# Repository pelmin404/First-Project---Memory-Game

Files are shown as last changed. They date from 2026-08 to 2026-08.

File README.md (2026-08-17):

# First-Project_Memory-Game

A small circuit board Simon type game based on Arduino's ATmega328P

This game is made to improve short term memory under load and just to spend time when bored.

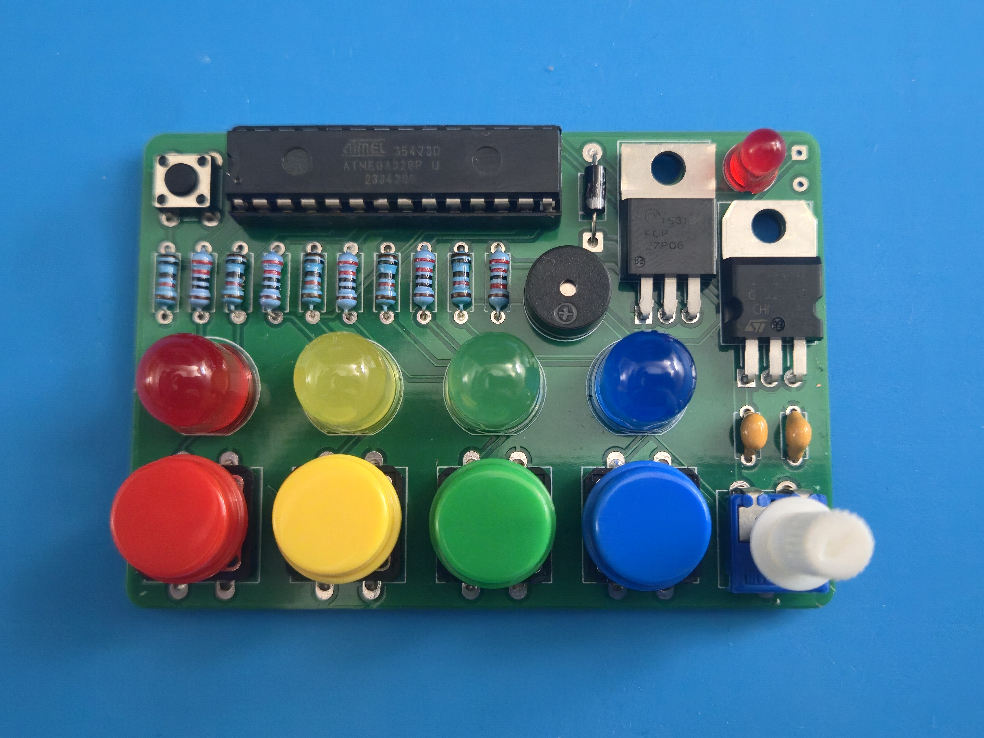
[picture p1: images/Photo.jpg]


# 🛠️ Technical Details
### The MCU is programmed with an internal 8 MHz clock

It works on the same MCU found in Arduino UNO R3 and a few others. It can be powered by a DC power source ranging from 7 to 35 volts, the files provided use a 9V input as an example. In the final iteration I added a power indicator with a MOSFET and an LED which is brighter the higher the input voltage with 9 volts being barely visible in order to indicate when the battery is almost at 7 volts, which may cause MCU instability. In order for the indicator system to work properly the combined voltage drop of the indicator LED and the following diode D6 should be as close as possible to the drop of the L7805CV or about 2 volts. The sound control potentiometer can be either logarithmic or regular, depending on preference. The small button on the top left corner of the board is used to reset the MCU and therefore the game if you encounter an electrical issue causing MCU instability or just really don't want to lose. The circular solder pad for the power source is ground (-).

## ⚠️ Please note that some mechanical switches may produce a noisy signal that forces the MCU to think you pressed the button multiple times

# 📼 Video examples

[Win example](https://github.com/pelmin404/First-Project_Memory-Game/blob/main/Videos/Win%20example.mp4)

[Loss example](https://github.com/pelmin404/First-Project_Memory-Game/blob/main/Videos/Loss%20example.mp4)

[Power indicator](https://github.com/pelmin404/First-Project_Memory-Game/blob/main/Videos/Power%20indicator.mp4)

# ⚙️ Part List

- [ATMEGA328P-PU](https://www.digikey.com/en/products/detail/microchip-technology/ATMEGA328P-PU/1914589)
- [MCU socket](https://www.digikey.com/en/products/detail/3m/4828-3004-CP/1133633?s=N4IgTCBcDaIMwFkCsAWAHABgLQDkAiIAugL5A)
- [Leo Sales Ltd. 10mm 2x6 Colors LED](https://www.microcenter.com/product/511285/leo-sales-ltd-10mm-2x6-colors-led)
- [Tactile Button Assortment](https://www.microcenter.com/product/427684/tactile-button-assortment)
- [L7805CV]()
- [5V 1.5A Linear Voltage Regulator - 7805 TO-220](https://www.adafruit.com/product/2164)
- 5 10 kΩ resistors
- 4 220 Ω resistors
- 1 22 kΩ resistor
- 1 0.33 μF capacitor
- 1 0.1 μF capacitor
- [Leo Sales Ltd. PCB Mounted Piezo Buzzer - 9x5.5mm (10 Pack)](https://www.microcenter.com/product/677928/leo-sales-ltd-pcb-mounted-piezo-buzzer-9x55mm-(10-pack))
- A 10 kΩ potentiometer, I used an ACP CA9-V10 footprint
- A 6 mm THT momentary push button
- Any 5 mm LED and a diode that fits the footprint, that have a total voltage drop of 2 V

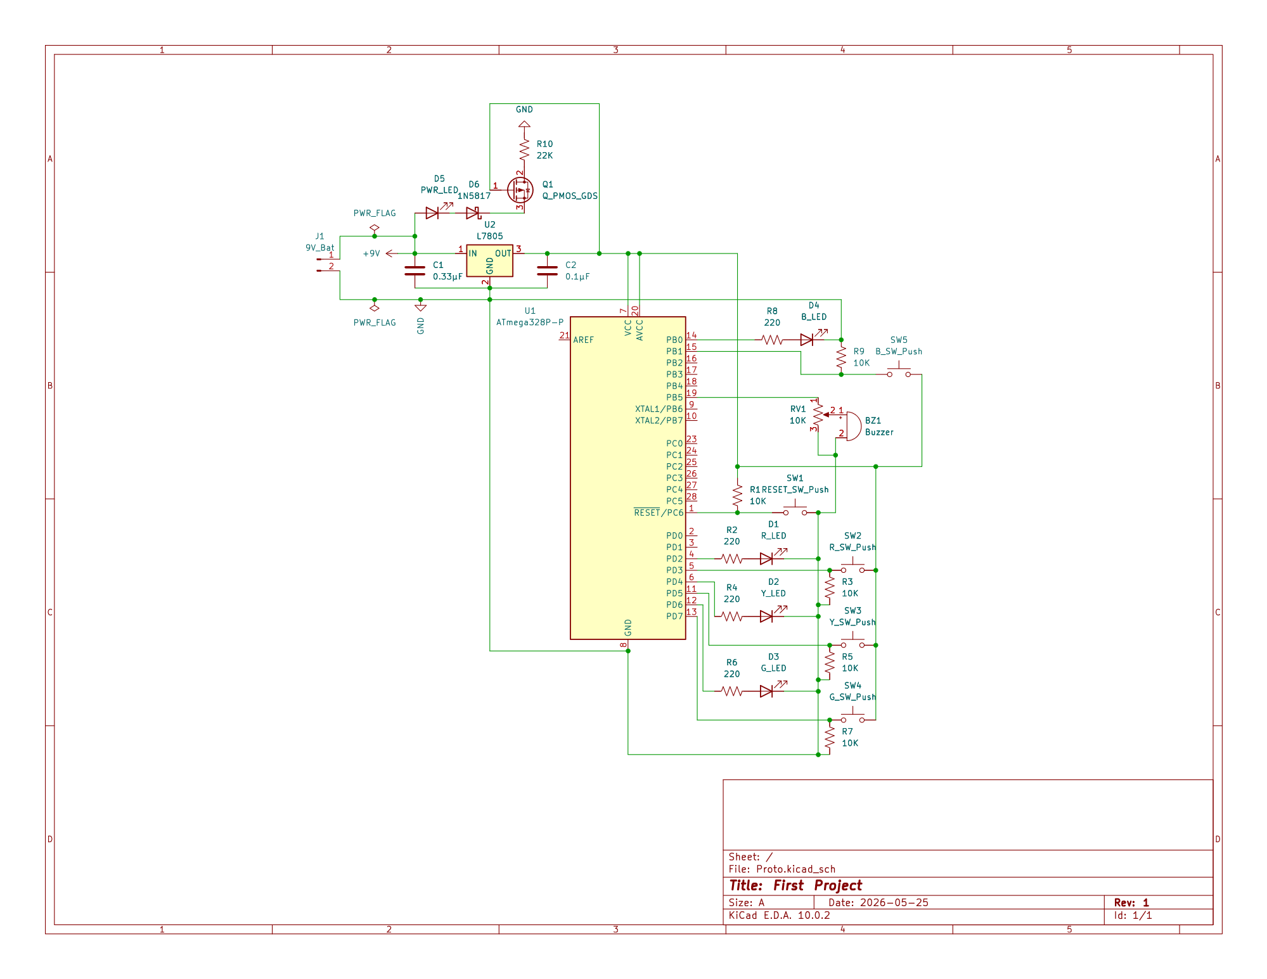
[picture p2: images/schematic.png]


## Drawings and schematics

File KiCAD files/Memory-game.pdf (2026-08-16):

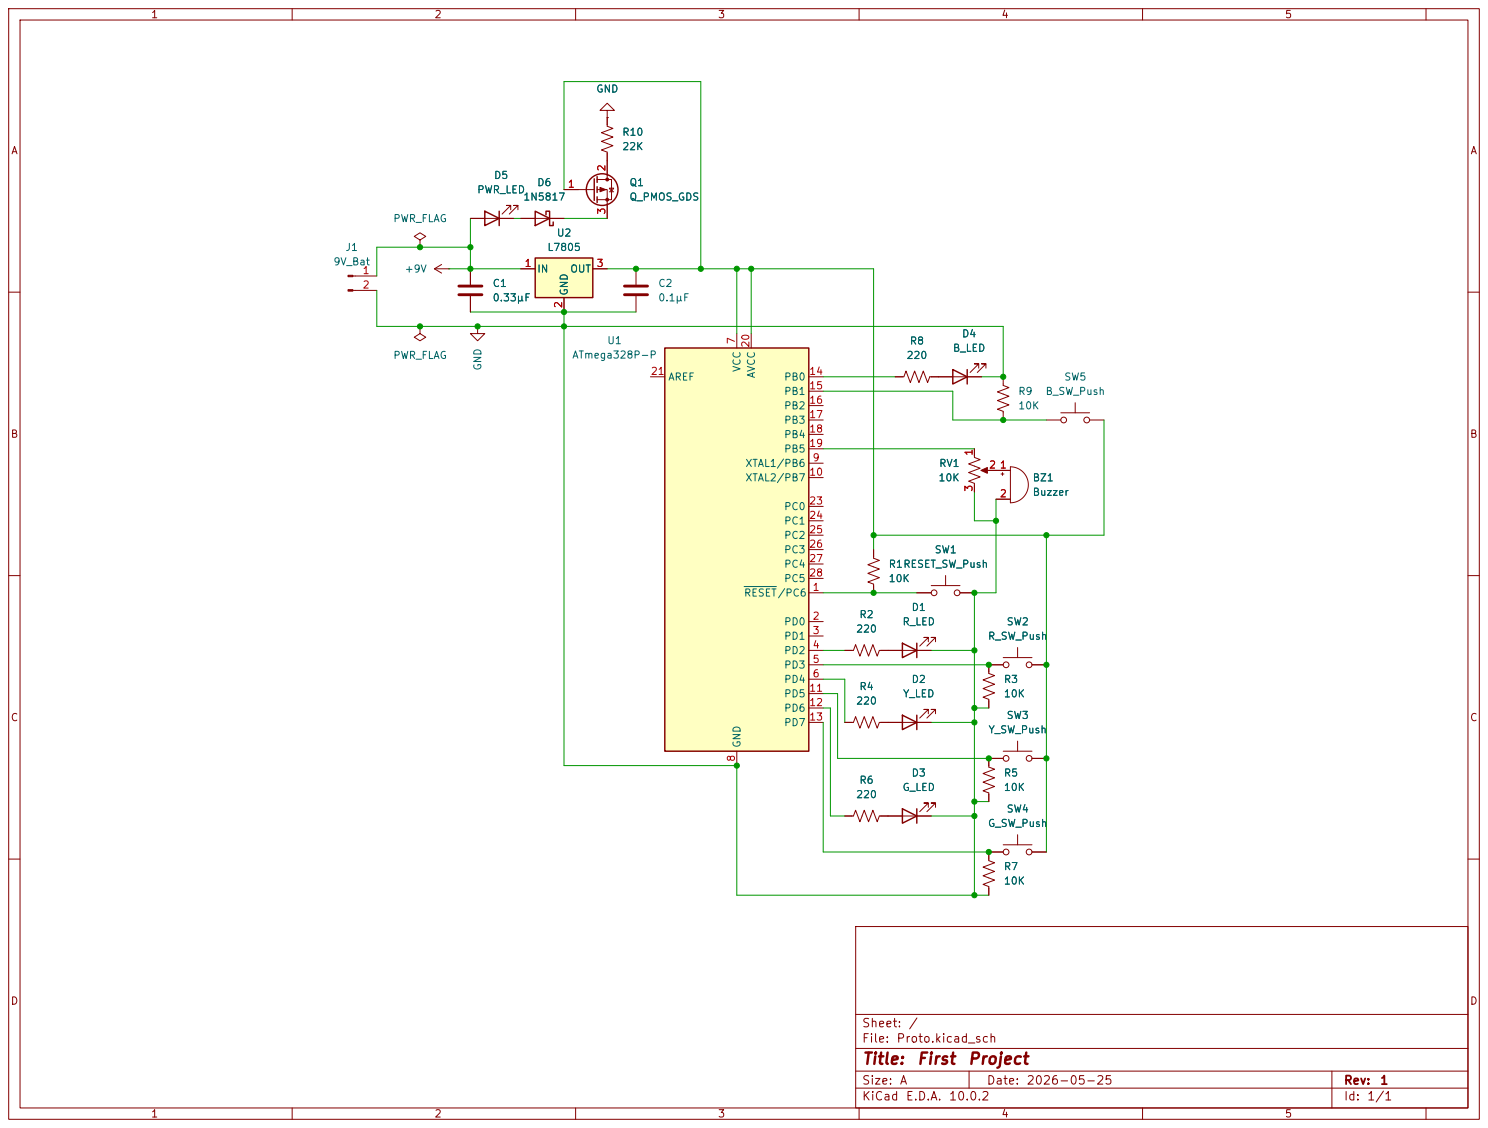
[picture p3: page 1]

Size: A | Rev: 1
KiCad E.D.A. 10.0.2 | Id: 1/1

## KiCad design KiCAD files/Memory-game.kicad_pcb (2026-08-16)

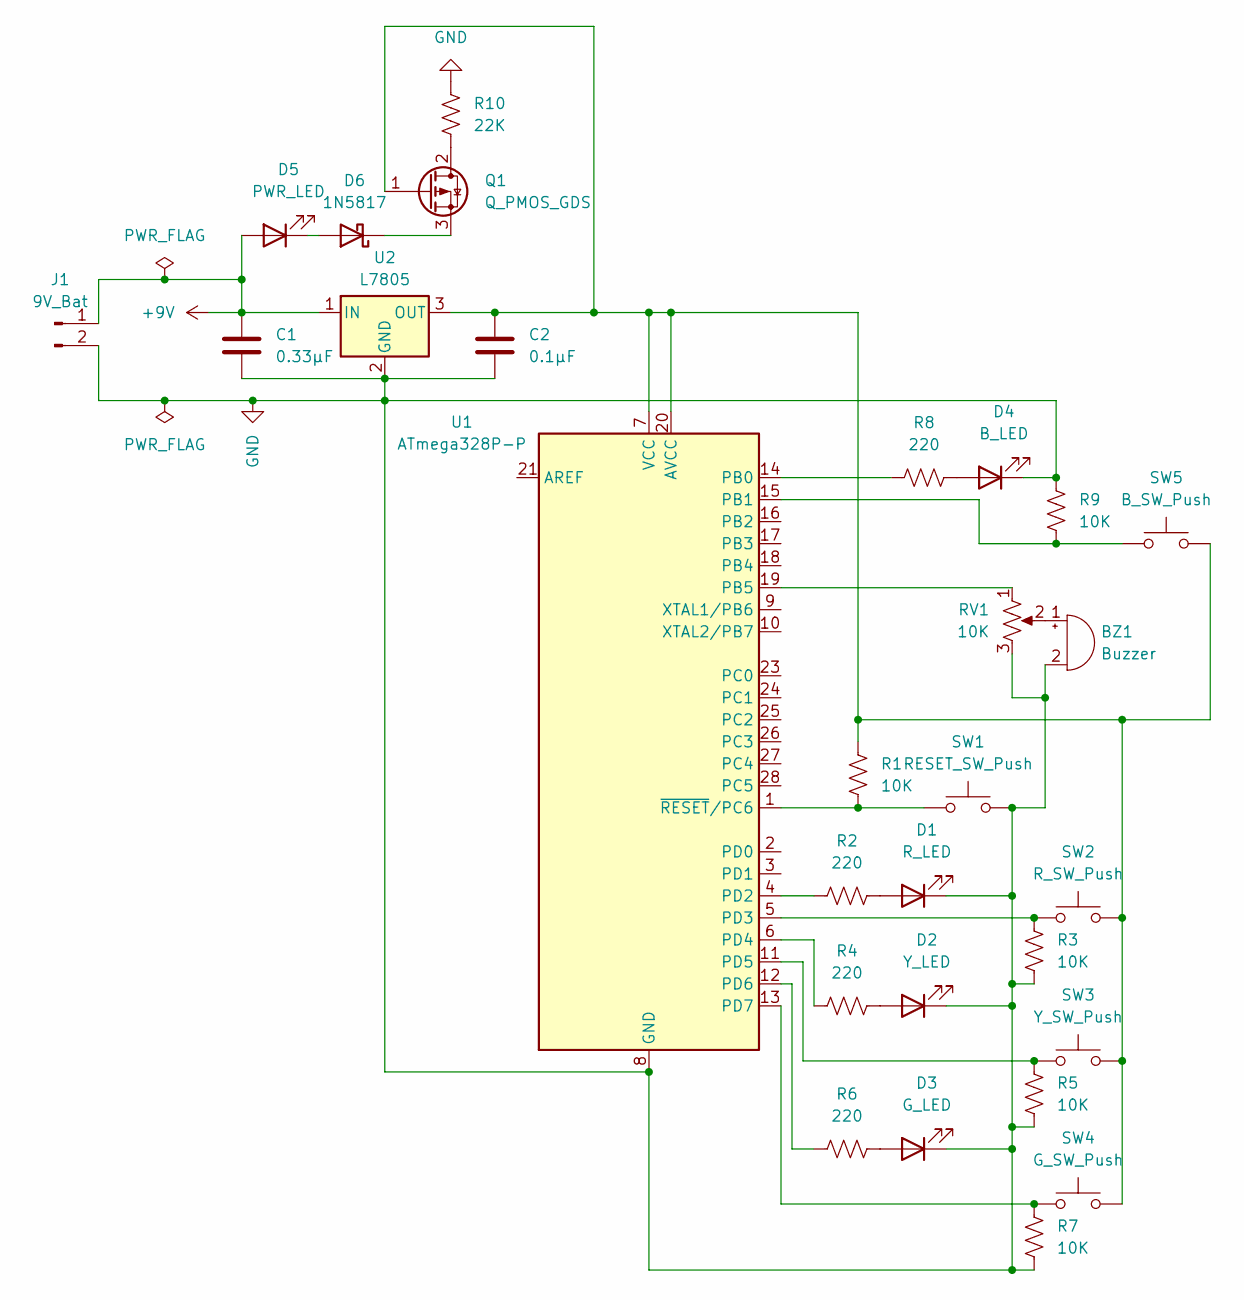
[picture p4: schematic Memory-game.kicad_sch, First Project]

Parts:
BZ1: Buzzer; MagneticBuzzer_PUI_AT-0927-TT-6-R
C1: 0.33µF; C_Disc_D4.7mm_W2.5mm_P5.00mm
C2: 0.1µF; C_Disc_D4.7mm_W2.5mm_P5.00mm
D1: R_LED; LED_D10.0mm
D2: Y_LED; LED_D10.0mm
D3: G_LED; LED_D10.0mm
D4: B_LED; LED_D10.0mm
D5: PWR_LED; LED_D5.0mm
D6: 1N5817; D_DO-41_SOD81_P10.16mm_Horizontal
J1: 9V_Bat; SolderWire-0.1sqmm_1x02_P3.6mm_D0.4mm_OD1mm
Q1: Q_PMOS_GDS; TO-220-3_Horizontal_TabDown
R1, R3, R5, R7, R9: 10K; R_Axial_DIN0207_L6.3mm_D2.5mm_P7.62mm_Horizontal
R2, R4, R6, R8: 220; R_Axial_DIN0207_L6.3mm_D2.5mm_P7.62mm_Horizontal
R10: 22K; R_Axial_DIN0207_L6.3mm_D2.5mm_P7.62mm_Horizontal
RV1: 10K; Potentiometer_ACP_CA9-V10_Vertical
SW1: RESET_SW_Push; SW_PUSH_6mm
SW2: R_SW_Push; SW_PUSH-12mm
SW3: Y_SW_Push; SW_PUSH-12mm
SW4: G_SW_Push; SW_PUSH-12mm
SW5: B_SW_Push; SW_PUSH-12mm
U1: ATmega328P-P; DIP-28_W7.62mm_Socket
U2: L7805; TO-220-3_Horizontal_TabDown

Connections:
+9V: C1.2, D5.2 (A), J1.1, U2.1 (IN)
GND: BZ1.2 (-), C1.1, C2.2, D1.1 (K), D2.1 (K), D3.1 (K), D4.1 (K), J1.2, R3.2, R5.2, R7.2, R9.2, R10.1, RV1.3, SW1.2, U1.8 (GND), U1.22 (GND), U2.2 (GND)
unnamed: BZ1.1 (+), RV1.2
unnamed: D1.2 (A), R2.1
unnamed: D2.2 (A), R4.1
unnamed: D3.2 (A), R6.1
unnamed: D4.2 (A), R8.1
unnamed: D5.1 (K), D6.2 (A)
unnamed: D6.1 (K), Q1.3 (S)
unnamed: Q1.2 (D), R10.2
unnamed: C2.1, Q1.1 (G), R1.1, SW2.2, SW3.2, SW4.2, SW5.2, U1.7 (VCC), U1.20 (AVCC), U2.3 (OUT)
unnamed: R8.2, U1.14 (PB0)
unnamed: R9.1, SW5.1, U1.15 (PB1)
unnamed: RV1.1, U1.19 (PB5)
unnamed: R2.2, U1.4 (PD2)
unnamed: R3.1, SW2.1, U1.5 (PD3)
unnamed: R4.2, U1.6 (PD4)
unnamed: R5.1, SW3.1, U1.11 (PD5)
unnamed: R6.2, U1.12 (PD6)
unnamed: R7.1, SW4.1, U1.13 (PD7)
unnamed: R1.2, SW1.1, U1.1 (~RESET/PC6)

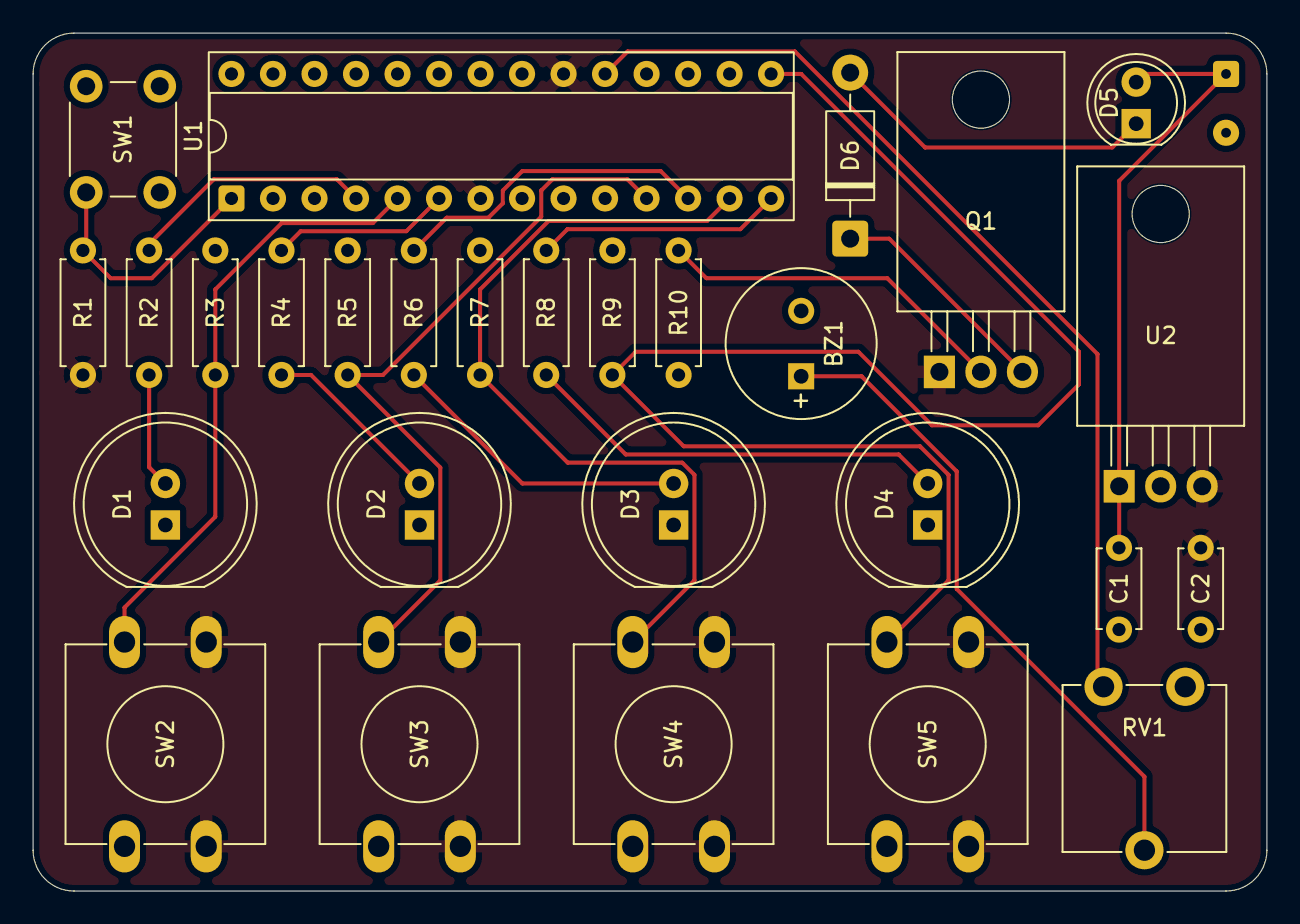
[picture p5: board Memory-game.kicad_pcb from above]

Board: 2 copper layers, 75.5 x 52.5 mm, 29 parts (0 on the bottom side), 21 nets.

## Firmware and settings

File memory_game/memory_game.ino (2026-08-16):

const int red = 2;
const int yellow = 4;
const int green = 6;
const int blue = 8;
const int redButton = 3;
const int yellowButton = 5;
const int greenButton = 7;
const int blueButton = 9;

// change this value to set the amount of levels
const int levels = 5;

int sequence[levels];
int buttonSequence[levels];
int level = 1;
int index;

void setup() {
  randomSeed(analogRead(A0));
  pinMode(red, OUTPUT);
  pinMode(yellow, OUTPUT);
  pinMode(green, OUTPUT);
  pinMode(blue, OUTPUT);
  pinMode(redButton, INPUT);
  pinMode(yellowButton, INPUT);
  pinMode(greenButton, INPUT);
  pinMode(blueButton, INPUT);
  pinMode(13, OUTPUT);
  for (int x = 0; x < levels; x++) {
    sequence[x] = random(1, 5);
  }
  delay(3000);
}

void loop() {
  for (int x = 0; x < level; x++) {
    index = sequence[x];
    if (index == 1) {
      digitalWrite(red, HIGH);
      tone(13, 500);
      delay(250);
      digitalWrite(red, LOW);
      noTone(13);
      delay(100);
    }
    else if (index == 2) {
      digitalWrite(yellow, HIGH);
      tone(13, 1000);
      delay(250);
      digitalWrite(yellow, LOW);
      noTone(13);
      delay(100);
    }
    else if (index == 3) {
      digitalWrite(green, HIGH);
      tone(13, 1500);
      delay(250);
      digitalWrite(green, LOW);
      noTone(13);
      delay(100);
    }
    else if (index == 4) {
      digitalWrite(blue, HIGH);
      tone(13, 2000);
      delay(250);
      digitalWrite(blue, LOW);
      noTone(13);
      delay(100);
    }
  }
  for (int x = 0; x < level; x++) {
    buttonSequence[x] = button();
    if (buttonSequence[x] != sequence[x]) {
      digitalWrite(red, HIGH);
      digitalWrite(yellow, HIGH);
      digitalWrite(green, HIGH);
      digitalWrite(blue, HIGH);
      tone(13, 100);
      delay(2000);
      digitalWrite(red, LOW);
      digitalWrite(yellow, LOW);
      digitalWrite(green, LOW);
      digitalWrite(blue, LOW);
      noTone(13);
      level = 0;
      for (int x = 0; x < levels; x++) {
      sequence[x] = random(1, 5);
      }
      return;
    }
  }

  delay(1000);
  level++;
  if (level == (levels + 1)) {
    digitalWrite(red, HIGH);
    tone(13, 500);
    delay(250);
    digitalWrite(yellow, HIGH);
    tone(13, 1000);
    delay(250);
    digitalWrite(green, HIGH);
    tone(13, 1500);
    delay(250);
    digitalWrite(blue, HIGH);
    tone(13, 2000);
    delay(250);
    digitalWrite(red, LOW);
    digitalWrite(yellow, LOW);
    digitalWrite(green, LOW);
    digitalWrite(blue, LOW);
    delay(250);
    digitalWrite(red, HIGH);
    digitalWrite(yellow, HIGH);
    digitalWrite(green, HIGH);
    digitalWrite(blue, HIGH);
    tone(13, 3000);
    delay(100);
    digitalWrite(red, LOW);
    digitalWrite(yellow, LOW);
    digitalWrite(green, LOW);
    digitalWrite(blue, LOW);
    noTone(13);
    delay(100);
    digitalWrite(red, HIGH);
    digitalWrite(yellow, HIGH);
    digitalWrite(green, HIGH);
    digitalWrite(blue, HIGH);
    tone(13, 3000);
    delay(100);
    digitalWrite(red, LOW);
    digitalWrite(yellow, LOW);
    digitalWrite(green, LOW);
    digitalWrite(blue, LOW);
    noTone(13);
    delay(100);
    digitalWrite(red, HIGH);
    digitalWrite(yellow, HIGH);
    digitalWrite(green, HIGH);
    digitalWrite(blue, HIGH);
    tone(13, 3000);
    delay(100);
    noTone(13);
    while (digitalRead(red) == HIGH || digitalRead(yellow) == HIGH || digitalRead(green) == HIGH || digitalRead(blue) == HIGH) {
      while (digitalRead(redButton) == HIGH) {
        digitalWrite(red, LOW);
        tone(13, 500);
      }
      while (digitalRead(yellowButton) == HIGH) {
        digitalWrite(yellow, LOW);
        tone(13, 1000);
      }
      while (digitalRead(greenButton) == HIGH) {
        digitalWrite(green, LOW);
        tone(13, 1500);
      }
      while (digitalRead(blueButton) == HIGH) {
        digitalWrite(blue, LOW);
        tone(13, 2000);
      }
    }
    delay(500);
    noTone(13);
    level = 0;
    for (int x = 0; x < levels; x++) {
    sequence[x] = random(1, 5);
    }
    delay(1000);
  }
}

int button() {
  while (digitalRead(redButton) == LOW && digitalRead(yellowButton) == LOW && digitalRead(greenButton) == LOW && digitalRead(blueButton) == LOW) {
  }
  if (digitalRead(redButton) == HIGH) {
    while (digitalRead(redButton) == HIGH) {
      digitalWrite(red, HIGH);
      tone(13, 500);
    }
    digitalWrite(red, LOW);
    noTone(13);
    return 1;
  }
  else {
  }
  if (digitalRead(yellowButton) == HIGH) {
    while (digitalRead(yellowButton) == HIGH) {
      digitalWrite(yellow, HIGH);
      tone(13, 1000);
    }
    digitalWrite(yellow, LOW);
    noTone(13);
    return 2;
  }
  else {
  }
  if (digitalRead(greenButton) == HIGH) {
    while (digitalRead(greenButton) == HIGH) {
      digitalWrite(green, HIGH);
      tone(13, 1500);
    }
    digitalWrite(green, LOW);
    noTone(13);
    return 3;
  }
  else {
  }
  if (digitalRead(blueButton) == HIGH) {
    while (digitalRead(blueButton) == HIGH) {
      digitalWrite(blue, HIGH);
      tone(13, 2000);
    }
    digitalWrite(blue, LOW);
    noTone(13);
    return 4;
  }
  else {
  }
}

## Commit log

2026-08-16 I finished this project before discovering Hack Club so no changes
    [Memory-game.kicad_pcb, Memory-game.kicad_sch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]
2026-08-17 added an image of the schematic
